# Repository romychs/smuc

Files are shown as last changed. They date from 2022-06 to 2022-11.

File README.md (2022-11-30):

# SMUC2

## Spectrum Multi Unit Controller

Оригинальный модуль SMUC (Scorpion & MOA Universal Controller), был расчитан на работу с клоном компьютера ZX Spectrum Scorpion.
Данный вариант является переработкой оригинальной схемы участниками форума zx-pk.ru и может использоваться с различными клонами, имеющими ZX-BUS.

Схема устройства основана на дискретной схеме SMUC Владислава Семченко (Vladislav Semchenko), реализована на CPLD фирмы ALTERA Евгением Ивановым (Ewgeny Ivanoff).
Некоторые изменения в схеме добавлены для увеличения совместимости с современными машинами (ZXM-Phoenix и др.) Валерием Ткачуком (Valery Tkachuck).
Печатная плата разработана и изготовлена Дмитрием Михальченковым (Dmitry Mikhalchenkov).

В папке [Originals](Originals) собраны материалы по варианту контроллера, разработанному участниками форума zx-pk.ru.

[Тема на форуме SMUC на дискретах и ПЛИС](https://zx-pk.ru/threads/1360-smuc-na-diskretakh-i-plis.html)

## Возможности контроллера
* Интерфейс IDE для подключения HDD, CD
* Память NVRAM 2k, для сохранения настроек
* Энергонезависимые часы типа DS1287, DS12887, M146818, 512ВИ1.
* Проограммная совместимость с ранее выпускавшимся SMUC 1.X, фирмой Scorpion, за исключением контроллера прерываний и интерфейса ISA8, которые в данной реализации отсутствуют.

## Мой вариант
В папке [My](My), приведена оцифрованая мной схема, печатная плата и герберы.

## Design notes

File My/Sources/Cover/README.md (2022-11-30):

# SMUC2

Декоративная крышка для платы SMUC2 в формате STL. Подходит только для моей версии платы, на других не проверял.

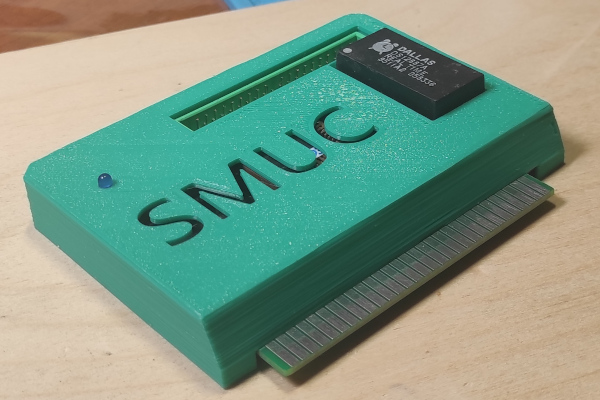
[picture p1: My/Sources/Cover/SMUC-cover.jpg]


Отпечатана на 3D-принтере:
* Пластик: PLA
* Сопло: 0.4мм
* Слой: 0.2мм
* Печать без поддержек, буквами SMUC вниз к столу.

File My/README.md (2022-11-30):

# SMUC2

Оцифрованная мной в EasyIDA схема контроллера SMUC2.

Схема, практически соответствует оригинальным герберам с исправлением замеченных ошибок. 
Печатная плата немного доработана, укорочены дорожки, передвинуты некоторые элементы, для более удобного монтажа, плата залита земляными полигонами.
Шаг ламелей краевого разъема 2.54мм под современные разъемы SL60 и SL62.

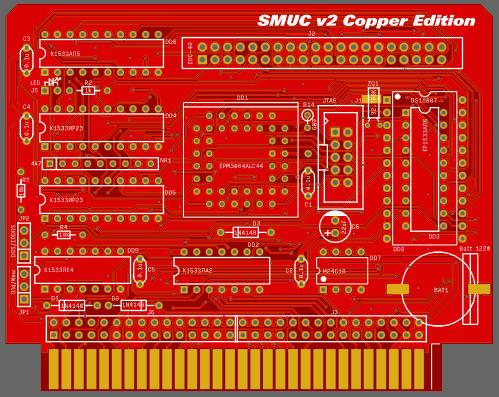
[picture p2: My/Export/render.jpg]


[Схема и печатная плата](Export)

[Герберы](Gerbers)

[Исходники для EasyEDA](Sources)

Все, что мое, то под лицензией BSD-3.

* Исправлена ошибка с сигналом SDA, замеченая VGalex.

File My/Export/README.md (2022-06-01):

# SMUC2

Схемы и монтажка в форматах PDF.

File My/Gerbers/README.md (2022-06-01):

# SMIC2

При заказе платы, не забудте указать, что плата имеет контакты на краю платы и нужен скос, для удобства вставки платы в слот.

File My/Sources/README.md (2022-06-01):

# SMUC2

Исходники проекта в [EasyIDA:](https://easyeda.com/)

Как использовать:
В редакторе, кликнуть на тулбаре в меню "Document" > "Open" > "EasyEDA Source", и выберите json-файл.

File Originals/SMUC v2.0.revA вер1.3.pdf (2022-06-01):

# SMUC v.2.0

rev.A

Руководству по подключению

http://witchcraft.org.ua/
http://zx.pk.ru/

Данное | руководство | поставляется | вместе | с | контроллером
SMUC v.2.0 rev.A.
В руководстве освещены вопросы подключения контроллера SMUC к ZX-Spectrum совместимому компьютеру, приведены монтажная и принципиальная схемы устройства, распиновка разъемов расширения по стандарту ZX-BUS. Описаны порты контроллера и принципы их программирования.
Составил | Михальченков | Дмитрий | Александрович | (Dmitry
Mikhalchenkov). Дата последней редакции 21.10.2009 г.

### 1 Введение

В данном документе описан переработанный вариант схемы SMUC (Scorpion & MOA Universal Controller). Теперь аббревиатура SMUC означает Spectrum Multi Unit Controller и рассчитана не только на компьютеры ZS Scorpion, а и на любые другие, соответствующие стандарту ZX-BUS. В отличие от оригинального SMUC, из схемы изъяты узлы, связанные с поддержкой ISA-шины и контроллера прерываний (PIC).
Схема устройства основана на дискретной схеме SMUC [1] Владислава Семченко (Vladislav Semchenko), реализована на CPLD фирмы ALTERA Евгением Ивановым (Ewgeny Ivanoff). Некоторые изменения в схеме добавлены для увеличения совместимости с современными машинами (ZXM-Phoenix и др.) Валерием Ткачуком (Valery Tkachuck). Печатная плата
разработана | и | изготовлена | Дмитрием | Михальченковым | (Dmitry
Mikhalchenkov).
Обсуждение сборки и наладки устройства проводится на форуме «Speccy - наш выбор!» [2].
Об использовании контроллера см. фирменное руководство «SMUC. Универсальный контроллер HDD, CMOS, NVRAM, IBM периферии. Руководство по подключению и работе» [3].

### 2 Назначение контроллера

Контроллер SMUC (Spectrum Multi Unit Controller) v2.0 rev.A служит для подключения к Spectrum-совместимому компьютеру накопителей на жестких (HDD), лазерных дисках (CD и DVD) и карт памяти CompactFlash (при использовании переходника CF>IDE), оснащенных интерфейсом IDE, позволяет работать с ними в системах TR-DOS¹
| | | | , Is-DOS, CP/M.
Кроме этого, контроллер оснащен микросхемой энергонезависимой памяти (NVRAM) объемом 2 Кбайта, предназначенной для сохранения различных настроек компьютера, параметров HDD, переменных Теневого Сервис-Монитора (при использовании на ПК Scorpion ZS 256) и т. д. В контроллере предусмотрена установка микросхемы энергонезависимых часов типа DS1287, DS12887, M146818, 512ВИ1.
Контроллер программно совместим с ранее выпускавшимся SMUC 1.X, фирмой Scorpion, за исключением контроллера прерываний и интерфейса ISA8, которые в данной реализации отсутствуют.

1 Перечисленный функционал доступен при установленном ПрофПЗУ. В противном случае необходимо пользоваться сторонним программным обеспечением и драйверами.

### 3 Принципиальная схема контроллера

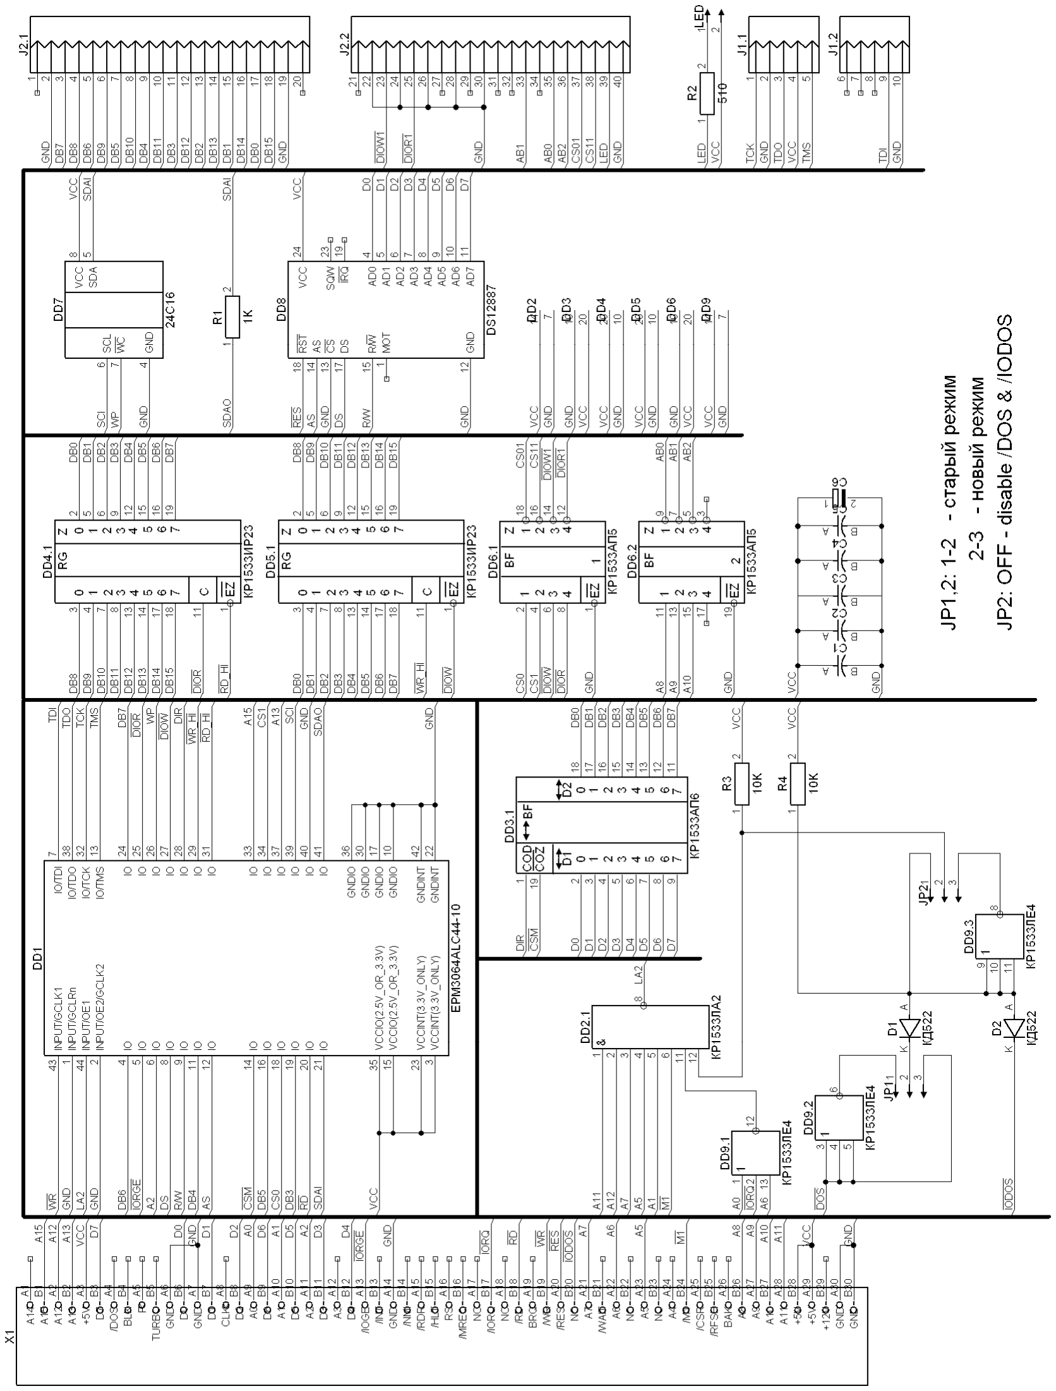
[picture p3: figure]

Рис. 1 – Принципиальная схема

Табл. 1. Список элементов
Обозначение на схеме | Наименование элемента
DD1 | EPM3064ALC44-10
DD2 | КР1533ЛА2
DD3 | КР1533АП6
DD4, DD5 | КР1533ИР23
DD6 | (КР555) КР1533АП5
DD7 | AT24C16
DD8 | DS12887
DD9 | КР1533ЛЕ4
D1, D2 | КД521
R1 | 1К 0,125Вт
R2 | 510 0,125Вт
R3, R4 | 10К 0,125Вт
С1 – С5 | 0,1мкФ
С6 | 10мкФ × 16В
J1 | IDC2X5M
J2 | IDC2X20M
J3² | HDR-2X30
LED | АЛ307
JP1, JP2 | JP1X3

### 4 Монтажная схема контроллера

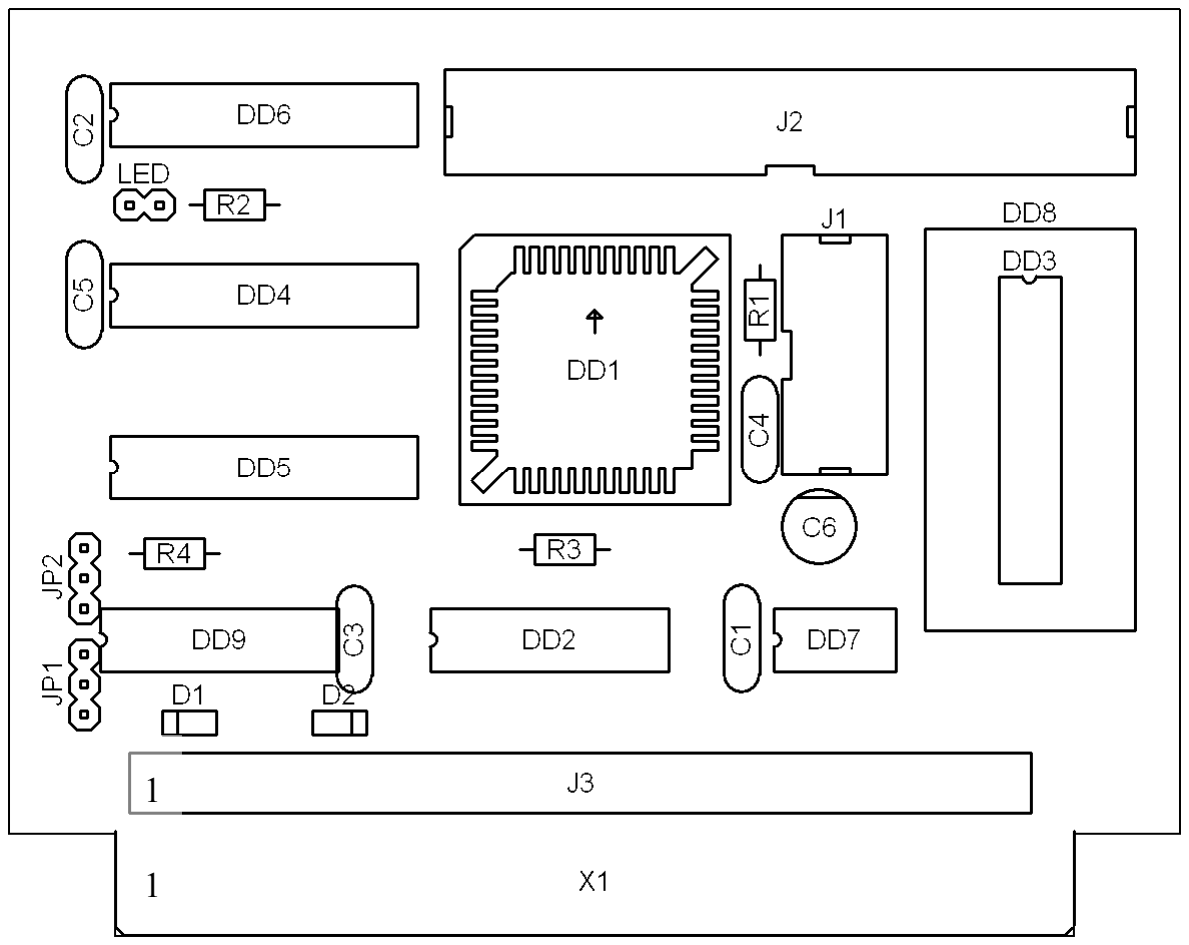
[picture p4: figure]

Рис. 2 – Монтажная схема

2 Штыревой разъем J3 на схеме не указан, на плате включается параллельно краевому разъему X1.

Первый контакт разъемов X1 и J3 находится слева.
Назначение разъемов:
— X1 — краевой ламельный разъем для подключения к системному разъему платы (см. Рис. 3);
— J1 — 10-контактный | штыревой | разъем | для | подключения
внутрисхемного программатора ByteBlaster, для программирования ПЛИС (см. Табл. 2) [4];
— J2 — 40-контактный стандартный разъем для подключения устройств IDE (см. Табл. 3);
— J3 — 60-контактный штыревой разъем для подключения к системному разъему платы (см. Рис. 3), включен параллельно разъему X1;
— JP1 и JP2 — 2-позиционные джампер-перемычки - селектор DOS режима с поддержкой сигнала /IODOS шины NemoBus v1.1 (инверсное значение D7 #EFF7). Селектор позволяет задавать режим активации портов контроллера (см. Табл. 4);
— LED — 2-контактный штыревой разъем для индикатора обращения к HDD (анод светодиода подключается к первому контакту, катод – ко второму).
Табл. 2. Распайка разъема
программатора ByteBlaster
Контакт | Сигнал | Назначение
1 | TCK | Тактовый сигнал
2 | GND | Сигнальная земля
3 | TDO | Данные с ПЛИС
4 | VCC | Напряжение питания
5 | TMS | Контроль автомата JTAG
6 | - | Не используется
7 | - | Не используется
8 | - | Не используется
9 | TDI | Данные в ПЛИС
10 | GND | Сигнальная земля
Табл. | 3. | Разъем | для
подключения IDE устройств
Контакт | Цепь | Контакт | Цепь
1 | Reset | 2 | GND
3 | D7 | 4 | D8
5 | D6 | 6 | D9
7 | D5 | 8 | D10
9 | D4 | 10 | D11
11 | D3 | 12 | D12
13 | D2 | 14 | D13
15 | D1 | 16 | D14
17 | D0 | 18 | D15
19 | GND | 20 | Свободный
21 | DRQ3 | 22 | GND
23 | IOWR | 24 | GND
25 | IORD | 26 | GND
27* | CRDY | 28 | CSEL
29* | DACK3 | 30 | GND
31* | IRQ14 | 32* | IO16
33 | ADR1 | 34* | PDIAG
35 | ADR1 | 36 | ADR2
37 | CS1 | 38 | CS3
39* | DA/SP | 40 | GND

* обозначены сигналы неиспользуемые при работе контроллера

Табл. 4. Перемычки для установки режима адресации контроллера
Положение перемычек | Описание
| Адресация контроллера в теневом режиме сигналом /DOS
| Адресация контроллера в теневом режиме сигналом /DOS или /IODOS
| Адресация контроллера в стандартном режиме (без учета сигналов /DOS и /IODOS)
1 | 2 | 3 | 1 | 2 | 3
| JP1 | | | JP2
1 | 2 | 3 | 1 | 2 | 3
| JP1 | | | JP2
1 | 2 | 3 | 1 | 2 | 3
| JP1 | | | JP2

Платы изготавливались на заводе без проверки. Перед сборкой внимательно осмотрите плату на наличие залипов между проводниками. Если они есть, обязательно их удалите. Также осмотрите контакты краевого разъема, наличие заусенцев может замкнуть контакты разъема при установке на материнскую плату.

При установке контроллера на материнскую плату, обязательно проверяйте совпадение контактов разъема контроллера и материнской платы. Перекосы и смещения недопустимы и могут привести к выходу контроллера и/или материнской платы из строя.

### 5 Подключение контроллера

Подключение контроллера к компьютеру предусмотрено посредством установки в слот расширения по стандарту ZX-BUS (Nemo-Bus). Для этого на плате контроллера размещен краевой ламельный разъем X1, шаг следования контактов – 2.54 мм, и штыревой разъем J3, если на материнской плате не предусмотрены слоты подключения.
В настоящее время шиной ZX-BUS оснащены следующие компьютеры:
- Kay-1024 3SL;
- Scorpion ZS 256;
- Pentagon 1024 SL;
- ZXM-Phoenix.
При установке платы контроллера в слот, удостоверьтесь, что плата расположена правильно, для этого обратитесь к документации Вашего компьютера. На компьютерах Kay-1024 и Scorpion ZS 256 контроллер вставляется в разъем платы так, что бы детали контроллера “смотрели” в сторону центрального процессора Z80.

Вид со стороны деталей

A14
A12
+5v
/DCDOS (3)
(2)
GND
GND
RAS (4)
A0
A1
A2
A3
/IORQCE
GND (kay!) (7)
/CSROMCE
RS (kay!) (5)

/BUSRQ
/RES
A7
A6
A5
A4
/CSROM
/BUSAK
A9
A11
+5v (kay!) (7)
GND

A15

D7

A13

/CSDS (1)

D0
D1
D2

AB
1 | 1
2 | 2
3 | 3
44
55
6 | 6
7 | 7
8 | 8
99
10 | 10
11 | 11
12 | 12
13 | 13
14 | 14
15 | 15
16 | 16
17 | 17
18 | 18
19 | 19
20 | 20
21 | 21
22 | 22
23 | 23
24 | 24
25 | 25
26 | 26
27 | 27
28 | 28
29 | 29
30 | 30
AB

D6
D5

TURBO (kay!) (6)

D3
D4
/INT
/NMI
/HALT
/MREQ
/IORQ
/RD
/WR

/WAIT

/M1
/RFSH
A8
A10
+5v (kay!) (7)
+12v (kay!) (7)
GND

Примечания:

(kay!) -- сигнал подключен только в компьютере KAY

(1) -- подключение 0 страницы ОЗУ (0xc000..0xffff в режиме zx-48kb) вместо ПЗУ. Сигнал имеется только в компьютерах Scorpion и KAY.
(2) -- контакт имеет разные назначения в разных моделях компьютеров.
В компьютере ZS-Scorpion ранних выпусков отмечен как РЕЗЕРВHЫЙ. Позже использовалься для подачи питания +12V на платы расширений. Hа turbo платах (зеленых) неиспользуемый контакт. В компьютере KAY на этот контакт выводится сигнал тактовой частоты 14Mhz.
(3) -- сигнал индицирующий подключение ПЗУ и портов Beta-Disk интерфейса.
(4) -- в компьютере Scorpion это и сигнал тактовой частоты процессора, и инвертированный и задержанный сигнал /RAS управляющий динамическим ОЗУ (по схеме Ленинград). В turbo версиях ZS-Scorpion сигнал не синхронный с тактовой частотой процессора. В компьютере KAY этот сигнал не является синхронным с тактовой частотой процессора и представляет из себя инвертированный сигнал /RAS. Частота всегда 3.5Mhz.
(5) -- сигнал имеется только в компьютере KAY. Это выход регистра 7FFD, отвечающий за банк ПЗУ (basic-128 или basic-48). Может управляться внешним устройством.
(6) -- сигнал устанавливается в 1 при включенном турбо-режиме. Выход типа открытый коллектор, то есть устройство расширения может принудительно отключить турбо-режим. Сигнал используется только в KAY.
(7) -- в компьютере ZS-Scorpion контакт не используется, используется только в KAY.
Рис. 3 – Сигналы шины ZX-BUS

Остальные Spectrum-совместимые машины либо имеют иную шину расширения, либо не имеют её вовсе. Для подключения контроллера к таким компьютерам, требуется произвести некоторые доработки на плате компьютера [5].
После подключения контроллера к системной плате компьютера необходимо подключить шлейф от IDE-устройства к разъему J2 контроллера. Подключение производится плоским 40 жильным кабелем.
Большинство шлейфов ATA содержат ключ (пломба вместо 20 контакта разъема шлейфа и отсутствующий штырек на разъеме контроллера), который позволяет избежать неправильное подключение устройств. Однако встречаются старые или самодельные шлейфы без ключа, будьте внимательней, проверьте, что подключение производится контакт в контакт, то есть 1-ый контакт к первому, 2-ой — к 2-му и т.д.
При необходимости подключите к разьему X6 светодиод типа АЛ307, плюс светодиода подсоединяется к конт. 2, минус к — конт. 1

### 6 Установка часов реального времени (СМОS-часов)

В стандартном варианте SMUC-контроллер поставляется без микросхемы часов реального времени (DS1287/DS12887), но при желании
пользователю | необходимо | только | вставить | эту | микросхему | в
соответствующую панельку на плате контроллера.
Эти микросхемы уже имеют встроенный генератор импульсов и источник резервного питания. Фирмой изготовителем гарантируется надежная работа источника в течении 10 лет. Следует помнить, что наличие или отсутствие ИМС часов никак не влияет на работу контроллера с HDD. Все установки параметров HDD и другие переменные, используемые Теневым Сервис-Монитором, и назначаемые пользователем, хранятся в ИМС
энергонезависимой | памяти | (NVRAM), | устанавливаемой | на | всех
контроллерах. Никаких дополнительных источников для работы NVRAM не требуется.
Микросхема DS1287/DS12887 может быть заменена импортными микросхемами других фирм производителей, а также советским аналогом — 512ВИ1 (при соответствующей доработке) [2].

### 7 Программирование SMUC

### 7.1 Распределение портов SMUC

Выборка SMUC как в оригинальной, так и переработанной (данной) схеме происходит в соответствии со значениями в Табл. 5:
Табл. 5. Условия выборки SMUC
/M1 /IORQ/DOS A15 A14 A13 A12 A11 A10 | | | | | | | | | A9 | A8 | A7 | A6 | A5 | A4 | A3 | A2 | A1 | A0
1 | 0 | 0 | DC | ISA | DC | 1 | 1 | DC | DC | DC | 1 | DC | 1 | ISA | ISA | DC | 1 | 0
Пояснения к таблице:
“1” и “0” – логическое значение соответствующих сигналов;
“DC” – сигнал используется в схеме для дешифровки портов базовых устройств SMUC и устройств ISA;
“ISA” – сигнал используется для дешифровки портов устройств ISA, в данной схеме не используется и по умолчанию принимается равным “1”; Для большинства базовых устройств SMUC сигналы A10, A9, A8 по умолчанию принимается равным “1”. Порты базовых устройств SMUC и устройств ISA дешифруются по сигналу A6: A6 = “0” – SMUC, A6 = “1” – ISA.
Выборка конкретных устройств происходит в соответствии со значениями Табл. 6 и Табл. 7 (действительно только для оригинального SMUC). При этом должно соблюдаться следующее условие: /M1 = “1”, /IORQ = “0”, /DOS = 0.

Табл. 6. Условия выборки базовых устройств SMUC
A15 | A14 | A13 | A12 | A11 | A10 | A9 | A8 | A7 | A6 | A5 | A4 | A3 | A2 | A1 | A0 | Порт | Устрой-ство
0 | 1 | 0 | 1 | 1 | 1 | 1 | 1 | 1 | 0 | 1 | 1 | 1 | 0 | 1 | 0 | #5FBA | VER
0 | 1 | 0 | 1 | 1 | 1 | 1 | 1 | 1 | 0 | 1 | 1 | 1 | 1 | 1 | 0 | #5FBE | REV
0 | 1 | 1 | 1 | 1 | 1 | 1 | 1 | 1 | 0 | 1 | 1 | 1 | 0 | 1 | 0 | #7FBA | FDD
0 | 1 | 1 | 1 | 1 | 1 | 1 | AB0 | 1 | 0 | 1 | 1 | 1 | 1 | 1 | 0 | #7FBE | PIC
1 | 1 | 0 | 1 | 1 | 1 | 1 | 1 | 1 | 0 | 1 | 1 | 1 | 0 | 1 | 0 | #DFBA | RTC
1 | 1 | 0 | 1 | 1 | 0 | 0 | 0 | 1 | 0 | 1 | 1 | 1 | 1 | 1 | 0 | #D8BE | IDE-HI
1 | 1 | 1 | 1 | 1 | 1 | 1 | 1 | 1 | 0 | 1 | 1 | 1 | 0 | 1 | 0 | #FFBA | SYS
1 | 1 | 1 | 1 | 1 | AB2 | AB1 | AB0 | 1 | 0 | 1 | 1 | 1 | 1 | 1 | 0 | #FFBE | IDE

Табл. 7. Условия выборки устройств ISA
A15 A14 A13 A12 A11 A10 | | | | | A9 | A8 | A7 | A6 | A5 | A4 | A3 | A2 | A1 | A0 | Порт | Устрой-ство
0 | AB4 AB3 | 1 | 1 | AB2AB1 AB0 | | | 1 | 1 | 1 | AB6AB5 | | 1 | 1 | 0 | #18E6 -#7FFE | ISA

ISA-шина SMUC поддерживает только карты расширения XT-ISA (или ISA-8), при этом адресные биты AB0-AB6 формируются из адресных сигналов процессора Z80, адресные биты AB7 и AB8 определяются битами данных порта #FFBA, а состояние адресных бит AB9-AB19 всегда установлено в “1”. Таким образом, поддержанными оказываются только 8-битные карты и устройства ISA с адресами 200h-3FFh (ранние ISA-карты использовали в дешифровке только адресные линии AB0-AB9). В адресном пространстве портов Z80 эти устройства занимают адреса #18E6 - #7FFE. Для простоты можно условно считать, что адреса устройств ISA формируются комбинацией одного из старших байт адреса #18, #38, #58 или #78 и одного из младших байт адреса #E6, #EE, #F6 или #FE (адресные биты AB0-AB2 дешифруют конкретный регистр устройства ISA).
Следует заметить, что явно видно “пересечение” адреса порта клавиатуры ZX-Spectrum #7FFE (клавиши “Space”, “SimbolShift”, “M”, “N”, “B”) с портами ISA 27Fh, 2FFh, 37Fh, 3FFh.

### 7.2 Описание портов SMUC

Ниже будет приведено описание портов базовых устройств SMUC, далее просто устройства SMUC.

### 7.2.1 Порты версии #5FBA (VER) и ревизии #5FBE (REV)

Являются только портами чтения и служат для идентификации SMUC. При отсутствии, по крайней мере, порта #5FBA подсистема ПрофПЗУ не “видит” SMUC и в дальнейшем работать с ним отказывается. Номер версии и ревизии задается битами D7, D6, D5 и D3 портов #5FBA и #5FBE. Формат

числа (номера) одинаков для обоих портов и указан в Табл. 8. Следует отметить, что номер версии (значение считанное из порта #5FBA) не может быть равным 7, так как именно в этом случае подсистема ПрофПЗУ признает отсутствие устройств SMUC в системе. Ниже приведены процедуры работы с портами версии (имеются в виду порты #5FBA и #5FBE).

Лис. 1 – Процедуры работы с портами версии

;----------------------------------------------------------------------------;Описание: Проверка наличия SMUC по определению версии
;входные данные: нет
;выходные данные: флаг CY - установлен - платы нет
; | D - байт версии
; | E - байт ревизии
;----------------------------------------------------------------------------
LAB_2425: | call | 0d51h
2428 3817 | jr | c,LAB_2441
242a 01ba5f | ld | bc,5fbah
242d ed78 | in | a,(c) | ;чтение байта версии
242f 3c | inc | a
2430 280f | jr | z,LAB_2441;флаг Z установлен - платы нет
2432 3d | dec | a
2433 cd4324 | call | LAB_2443 ;преобразуем байт
2436 57 | ld | d,a
2437 01be5f | ld | bc,5fbeh
243a ed78 | in | a,(c) | ;чтение байта ревизии
243c cd4324 | call | LAB_2443 ;преобразуем байт
243f 5f | ld | e,a
2440 c9 | ret
LAB_2441: | scf
2442 c9 | ret
;----------------------------------------------------------------------------;Описание: Преобразование версии
;входные данные: А - до преобразования
;выходные данные: А - байт после преобразования ;----------------------------------------------------------------------------
LAB_2443: | ld | b,a
2444 0f | rrca
2445 0f | rrca
2446 0f | rrca
2447 e601 | and | 01h
2449 4f | ld | c,a
244a 78 | ld | a,b
244b 07 | rlca
244c 07 | rlca
244d 07 | rlca
244e b1 | or | c
244f e607 | and | 07h
2451 c9 | ret

### 7.2.2 Порт виртуальных дисководов #7FBA (FDD)

Порт доступен на запись и чтение. Порт представляет собой ячейку памяти на 2 бита. Назначение бит показано в Табл. 9.

Табл. 8. Формат номера
версии и ревизии SMUC
Значения бит данных
D7 | D6 | D5 | D3 | Номер
0 | 0 | 0 | 0 | 0
0 | 0 | 1 | 1 | 1
0 | 1 | 0 | 0 | 2
0 | 1 | 1 | 1 | 3
1 | 0 | 0 | 0 | 4
1 | 0 | 1 | 1 | 5
1 | 1 | 0 | 0 | 6
1 | 1 | 1 | 1 | 7

Табл. 9. Назначение бит
порта виртуальных дисководов Биты
порта
#7FBA

Назначение бит

D7 | Дисковод A: 0 – виртуальный; 1 - реальный
D6 | Дисковод B: 0 – виртуальный; 1 - реальный

7.2.3 Порты контроллера прерываний #7FBE/#7EBE (PIC).
Данные порты служат для обмена данными с микросхемой контроллера прерываний i8259A/i8259 (КР1810ВН59А/КР580ВН59). Это устройство используется только в оригинальном SMUC и в данной схеме не поддерживается, по той причине, что его основная задача заключалась в поддержке ISA-шины. Тем не менее, для полноты картины, тут приведены общие данные по контроллеру прерываний.
Управление микросхемой i8259A и ее аналогов производится через два порта – #7FBE/#7EBE. Назначение портов приведено в Табл. 10.

Табл. 10. Назначение портов PIC

Порт | Регистры PIC
OUT #7EBE | ICW1, OCW2, OCW3
OUT #7FBE | ICW2, ICW3,ICW4, OCW1(IMR)
IN #7EBE | IRR, ISR
IN #7FBE | IMR

Более детальную информацию по контроллеру прерываний i8259A следует искать в описании на микросхему.

7.2.4 Порт часов реального времени #DFBA (RTC).
Обмен данными с микросхемой CMOS RTC Motorola MC146818A или ее аналогами (Интеграл КР512ВИ1, Dallas DS1287, Benchmarq BQ3287 и др.) производится через два порта чтения/записи с адресом #DFBA. Выборка необходимого порта осуществляется битом D7 порта #FFBA. Назначение портов RTC приведено в Табл. 11.

Табл. 11. Назначение портов RTC
Бит D7 порта #FFBA | Порт | Регистр RTC
| OUT #DFBA IN #DFBA | Регистр адреса 0 Регистр данных
| OUT #DFBA IN #DFBA | Регистр данных 1 -

Функционально микросхема RTC представляет собой массив из 64-128 (в зависимости от типа микросхемы) регистров данных. Регистры #00-#0D используются для хранения значений времени и управления часами, а регистры #0E-#7F являются ОЗУ. Назначение регистров RTC приведено в Табл. 12.

Табл. 12. Назначение регистров RTC
Адрес регистра | Назначение
#00 | Секунды

#01 | Секунды будильника

#02 | Минуты

#03 | Минуты будильника

#04 | Часы

#05 | Часы будильника

#06 | День недели

#07 | Число

#08 | Месяц

#09 | Год

#0A | Регистр A

#0B | Регистр B

#0C | Регистр C

#0D | Регистр D

#0E-#7F | ОЗУ общего назначения

Более детальную информацию по RTC следует искать в описании на микросхему.

7.2.5 Порты ATA.
Для работы с устройствами ATA (HDD, CD/DVD-ROM, CF и др.) в SMUC имеется массив портов #F8BE-#FFBE (АТА) и регистр старшего байта данных #D8BE (IDE-HI). Кроме того, для выбора двух полукомплектов регистров ATA используется бит D7 порта #FFBA. Назначение и порты регистров ATA приведены в Табл. 13.

Табл. 13. Назначение регистров ATA
D7 порта #FFBA | Порт SMUC | Порт IBM PC | Адресация CHS | Адресация LBA(28) Бит
OUT | IN | OUT | IN
0 | #F8BE | 1F0h | Data | Data | Data | Data
| #F9BE | 1F1h | Features | Error | Features | Error
| #FABE | 1F2h | Sector Count | Sector Count | Sector Count | Sector Count
| #FBBE | 1F3h | Sector Number | Sector Number | LBA (7:0) | LBA (7:0)
| #FCBE | 1F4h | Cylinder Low | Cylinder Low | LBA (15:8) | LBA (15:8)
| #FDBE | 1F5h | Cylinder High | Cylinder High | LBA (23:16) | LBA (23:16)
| #FEBE | 1F6h | Device/Head | Device/Head | Device, LBA (27:24) | Device, LBA (27:24)
| #FFBE | 1F7h | Command | Status | Command | Status
1 | #FEBE | 3F6h | Device Control | Alternative Status | Device Control | Alternative Status

Регистр старшего байта данных #D8BE нужен для временного хранения четного байта данных. Поскольку регистр данных ATA (Data) 16-битный, то для согласования с 8-битной шиной данных Z80 требуется временный буфер в виде регистра IDE-HI.
Регистр #FEBE (Device/Head) имеет следующее значение бит:
D0-D3 – в режиме адресации CHS определяют номер головки, в режиме адресации LBA являются старшими битами логического адреса блока (сектора);
D4 – DEV (Device), выбор устройства, при DEV=0 выбрано ведущее, при DEV=1 – ведомое;
D5=1, устаревший;
D6 – L (LBA), режим адресации, L=0 – CHS, L=1 – LBA;
D7=1, устаревший.
Регистр #FEBE (Device Control) имеет следующее значение бит:
D0=0;
D1 – nIEN (Interrupt Enable), инверсный бит разрешения прерывания, nIEN=0 – выбранное устройство может вырабатывать сигнал INTRQ через тристабильный выход;
D2 – SRST (Software Reset), программный сброс, действует все время пока SRST=1. Оба устройства (Master и Slive) воспринимают этот сигнал одновременно. На ATAPI-устройства сигнал не влияет;
D3=1 – зарезервирован;

D4-D6=0 – зарезервированы;
D7 – HOB (High Order Byte), определен в режиме LBA48, любая запись в регистры командного блока (Command Block Registers) сбрасывает этот бит в 0. Для режимов CHS и LBA28 (обычный режим LBA) D7=0.
Более детальную информацию по работе устройств ATA следует искать в описании стандарта ATA.

### 7.2.6 Системный порт SMUC #FFBA (SYS)

Служит для аппаратного сброса ISA, PIC и АТА, управления адресными линиями AB7 и AB8 ISA-шины, управления PIC и NVRAM, а также выборки дополнительных регистров. Назначение битов порта SYS приведено в Табл. 14.
Табл. 14. Назначение бит порта SYS
Бит порта | OUT #FFBA | IN #FFBA
D0 | RESET, 0 – сброс ISA, PIC, ATA | -
D1 | AB7 ISA* | -
D2 | AB8 ISA* | -
D3 | IE (Interrupt Enable), 1 – разрешение прерываний от PIC* | ?
D4 | SDA I² C [OUT] | -
D5 | WP I² C(Write Protect), 1 – запрет записи | -
D6 | SCL I² C | SDA I 2 C [IN]
D7 | SR (Shadow Register), 1 – переключение на теневые регистры | IRQ1 [IN]

### 8 Гарантии и сервисное обслуживание

Платы контроллера поставляются в двух вариантах поставки:
- Пустая плата для самостоятельной сборки с документацией;
- Конструктор для самостоятельной сборки с прошитой микросхемой EPM3032/EPM3064 и документацией;
- Плата собранная и готовая к эксплуатации.
Все собранные платы тестируются на компьютерах Scorpion ZS-256 и Kay-1024. Т.е. пользователю они поставляются в рабочем состоянии.
Мы не несем ответственности в случае неправильной установки или подсоединения устройства к компьютеру или жесткому диску, повлекшему в результате этого, к выходу устройства или компьютера из строя.
При подключении жестких дисков стоит учитывать, что жесткие диски требовательны к источнику питания. Убедитесь, достаточно ли мощный Ваш блок питания для работы жесткого диска (требования по питанию обычно приводятся на корпусе жесткого диска).

### 9 Список литературы

1. В.В.Семченко «SMUC на дискретных компонентах», Харьков, 2006;
2. Форум «Speccy - наш выбор!», Тема «SMUC на дискретах и ПЛИС» http://zx.pk.ru/showthread.php?t=1360
3. SMUC. Универсальный контроллер HDD, CMOS, NVRAM, IBM периферии. Руководство по подключению и работе v.1.2. Фирма Скорпион & МОА. СПб, 1996-97;
4. Программатор "ByteBlaster". http://msevm.com/main/prog/bb2.htm
5. ZX-BUS. Spectrum Expert#1-2. 2002.
6. Контроллер IDE для ZX-BUS по схеме NEMO. NedoPC group, Москва, 2004;

### 10 Доработки и исправления на плате SMUC v2.0 rev.A

### 10.3 Добавление сигнала /DOS

В ревизии А плат имеется ошибка – сигнал /DOS не заведен с разъема в схему. Для исправления ошибки необходимо проводом типа МГТФ припаять перемычку между контактом A4 разъема X1 и ножками 3-4-5 микросхемы DD9.

### 10.4 Доработка для корректной работы на компьютерах с

шиной NemoBUS.
Платы ревизии А имеют ошибку в схеме формирования сигнала /IORGE, что приводит к конфликту между портами контроллера и материнской платы, при подключении к компьютерам, типа Kay-1024, ZXM-Phoenix 1024, Pentagon-1024 v2.2. На компьютерах Scorpion ZS-256 контроллер корректно работает как с, так и без доработки.
Для исправления ошибки необходимо выполнить следующие действия:
1. Отрезать сигнал /IORQ от ноги 2 DD9 ЛЕ4 (см. Рис.4, вид платы со стороны монтажа), на эту ногу подать "землю" (припаять перемычку проводом МГТФ между 7 и 2 ногами микросхемы DD9).
2. Отрезать от земли ногу 1 DD1 ALTERA EPM3032/EPM3064 (см. Рис.5, вид платы со стороны пайки) и подать на нее сигнал /IORQ с краевого разъема, контакт B17.
3. Прошить DD1 ALTERA EPM3032/EPM3064 с помощью ByteBlaster-MV последней прошивкой (см. http://witchcraft.org.ua/).

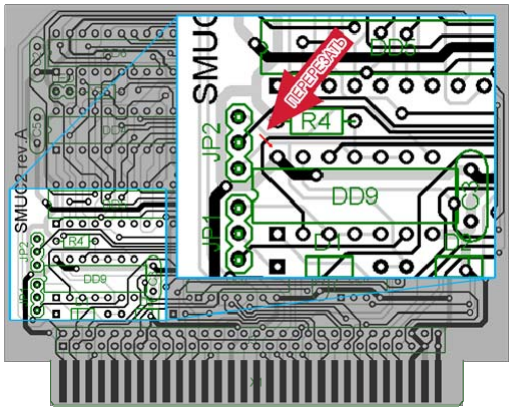
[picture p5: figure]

Рис. 4 – Доработка платы. Места разреза дорожек.

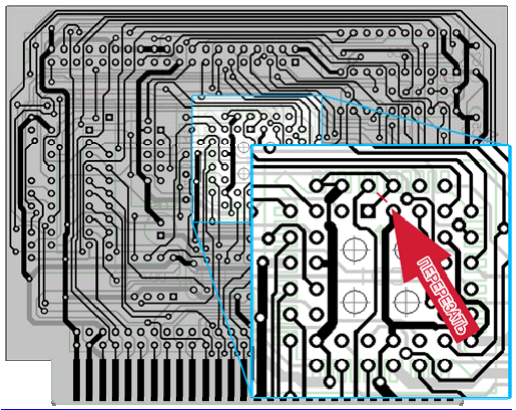
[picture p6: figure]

Рис. 5 – Доработка платы. Места разреза дорожек.

### 10.5 Повышение надежности работы жестких дисков

В разрыв сигналов /DIOR1 и /DIOW1, идущих на разъем IDE, необходимо поставить сопротивления на 27-100 Ом, которые уменьшают помехи на этих линиях, и увеличивает надежность работы жестких дисков. Схема должна выглядеть так:

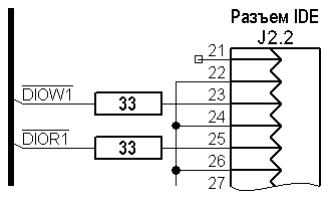
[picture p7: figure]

Рис. 6 – Повышение надежности работы жестких дисков

СОДЕРЖАНИЕ

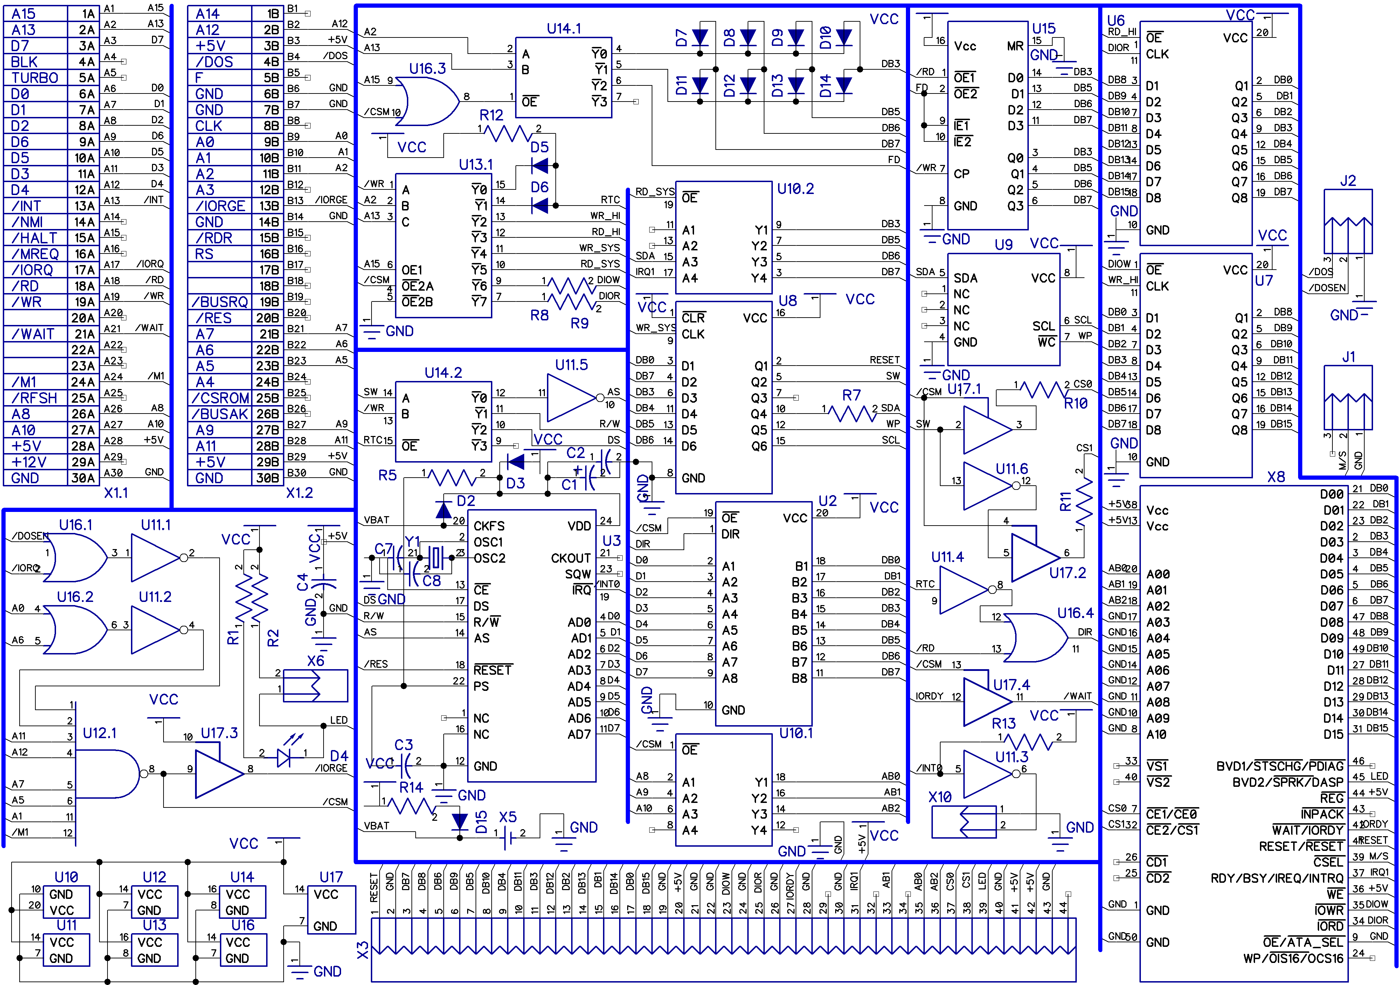
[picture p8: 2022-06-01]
Originals/Discrete/Schematics_From_krotan.gif

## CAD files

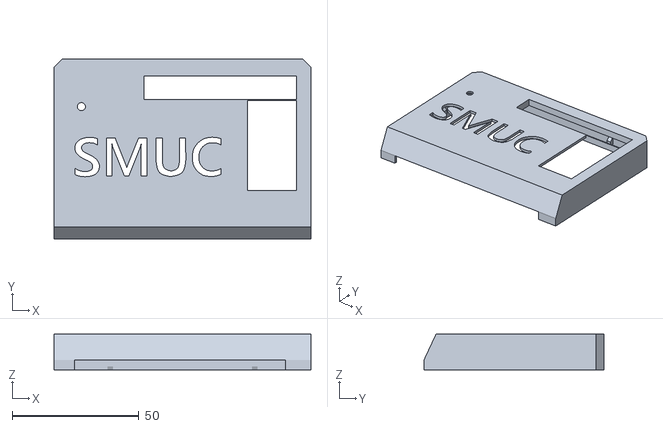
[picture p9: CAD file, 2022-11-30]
My/Sources/Cover/SmucCover.stl
101.4 x 71.0 x 14.2

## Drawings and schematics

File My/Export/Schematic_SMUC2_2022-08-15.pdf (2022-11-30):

## CPLD

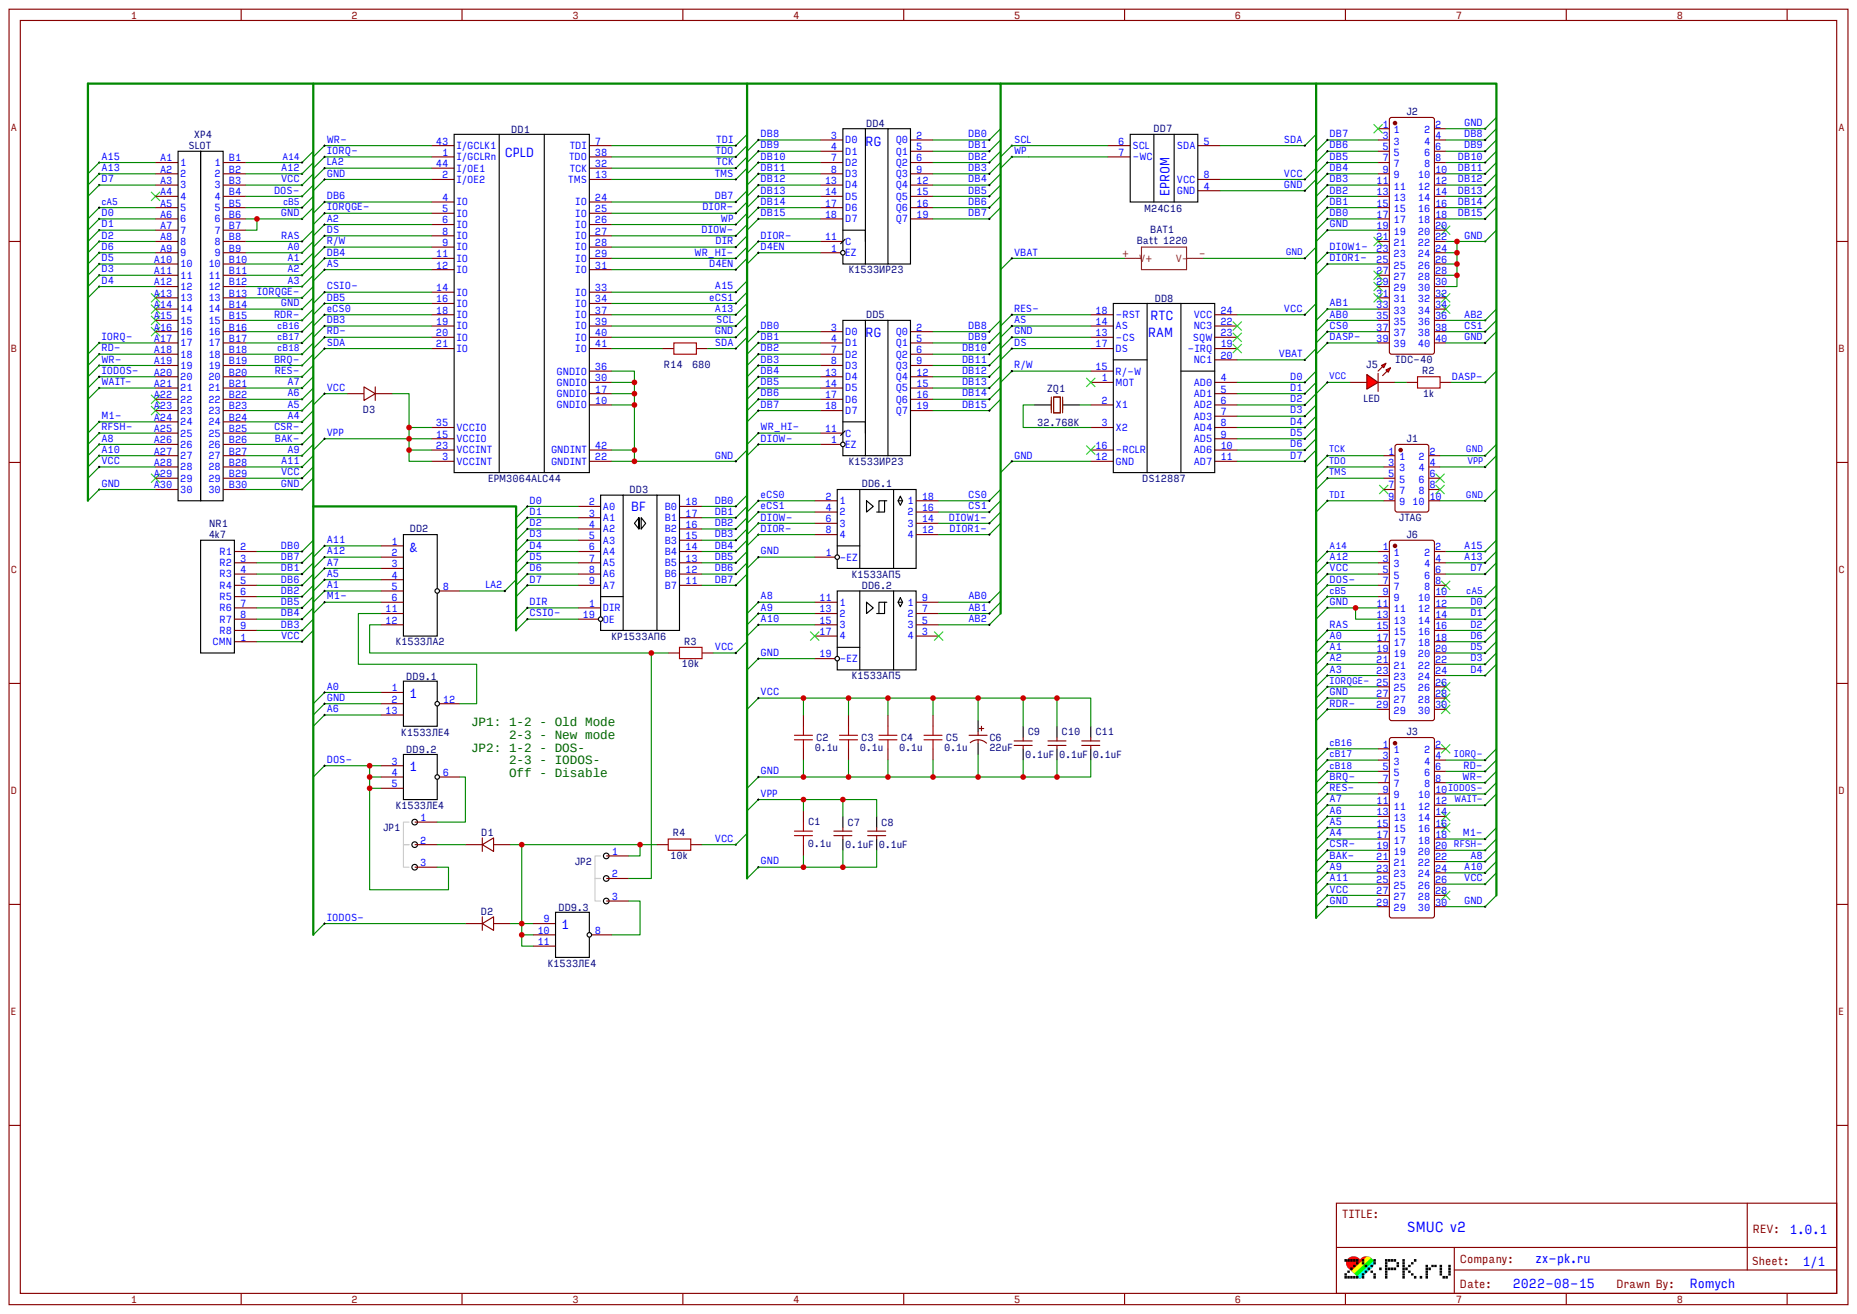
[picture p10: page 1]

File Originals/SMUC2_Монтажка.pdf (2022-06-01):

# SMUC v2.0 rev.B

## монтажная схема

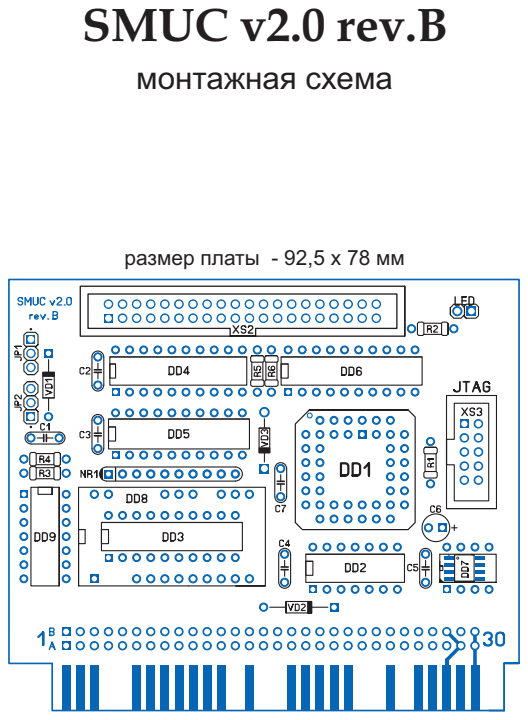
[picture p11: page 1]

размер платы - 92,5 х 78 мм

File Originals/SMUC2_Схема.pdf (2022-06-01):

# CPLD

3 | D0 4 | D1 7 | D2 8 | D3 13 | D4 14 | D5 17 | D6 18 | D7

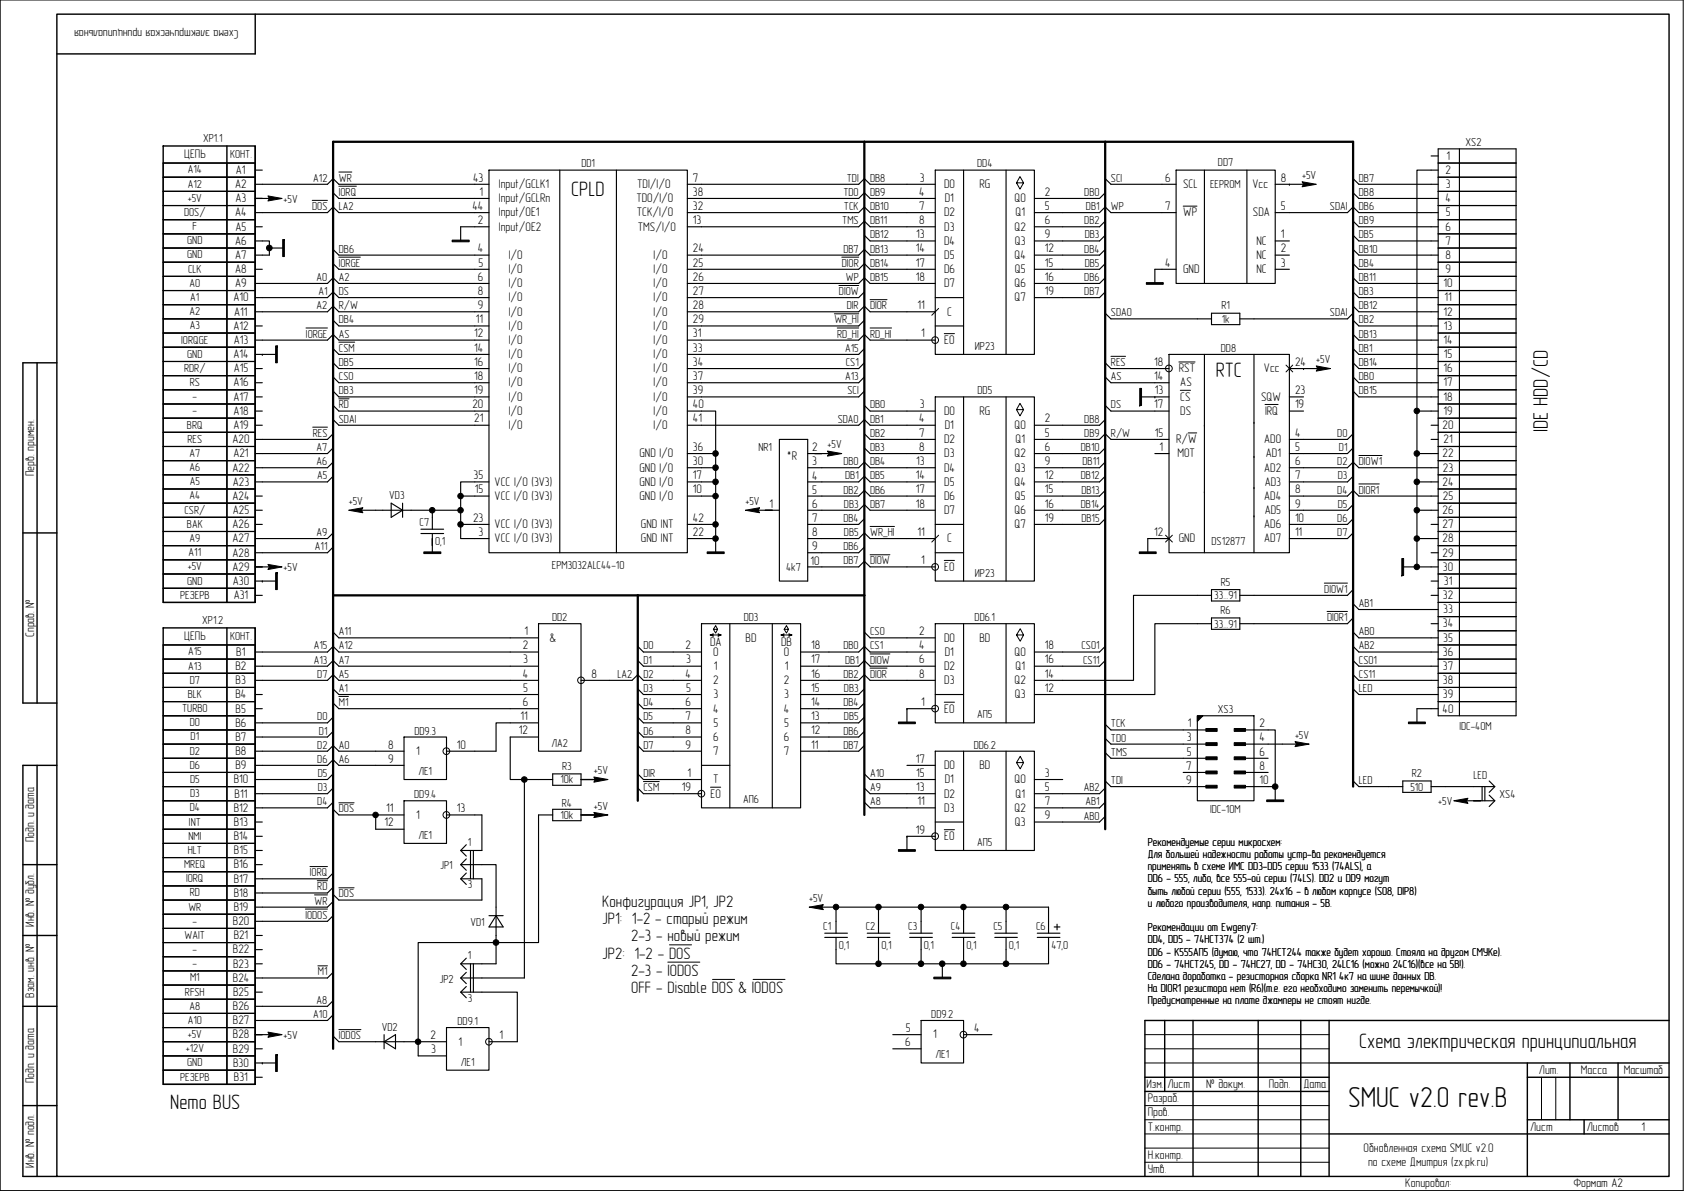
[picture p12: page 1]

Èíâ. ¹ ïîäë. Ïîäï. è äàòà Âçàì. èíâ. ¹ Èíâ. ¹ äóáë. Ïîäï. è äàòà Ñïðàâ. ¹ Ïåðâ. ïðèìåí.

NMI | B14
HLT | B15
MREQ | B16
IORQ | B17
RD | B18
WR | B19
- | B20
WAIT | B21
- | B22
- | B23
M1 | B24
RFSH | B25
A8 | B26
A10 | B27
+5V | B28
+12V | B29
GND | B30

Ðåêîìåíäóåìûå ñåðèè ìèêðîñõåì:
Äëÿ áîëüøåé íàäåæíîñòè ðàáîòû óñòð-âà ðåêîìåíäóåòñÿ
ïðèìåíÿòü â ñõåìå ÈÌÑ DD3-DD5 ñåðèè 1533 (74ALS), à
DD6 - 555, ëèáî, âñå 555-îé ñåðèè (74LS). DD2 è DD9 ìîãóò
áûòü ëþáîé ñåðèè (555, 1533). 24x16 - â ëþáîì êîðïóñå (SO8, DIP8)
è ëþáîãî ïðîèçâîäèòåëÿ, íàïð. ïèòàíèÿ - 5Â.

Ðåêîìåíäàöèè îò Ewgeny7:
DD4, DD5 - 74HCT374 (2 øò.)
DD6 - Ê555ÀÏ5 (äóìàþ, ÷òî 74HCT244 òàêæå áóäåò õîðîøî. Ñòîÿëà íà äðóãîì ÑÌÓÊå).
DD6 - 74HCT245, DD - 74HC27, DD - 74HC30, 24LC16 (ìîæíî 24C16)(âñå íà 5Â!).
Ñäåëàíà äîðàáîòêà - ðåçèñòîðíàÿ ñáîðêà NR1 4ê7 íà øèíå äàííûõ DB.
Íà DIOR1 ðåçèñòîðà íåò (R6)(ò.å. åãî íåîáõîäèìî çàìåíèòü ïåðåìû÷êîé)!
Ïðåäóñìîòðåííûå íà ïëàòå äæàìïåðû íå ñòîÿò íèãäå.

Ñõåìà ýëåêòðè÷åñêàÿ ïðèíöèïèàëüíàÿ

ÐÅÇÅÐÂ | B31

Èçì. | Ëèñò | ¹ äîêóì. | Ïîäï. | Äàòà
Ðàçðàá.
Ïðîâ.
Ò.êîíòð.

Îáíîâëåííàÿ ñõåìà SMUC v2.0
ïî ñõåìå Äìèòðèÿ (zx.pk.ru)

Í.êîíòð.

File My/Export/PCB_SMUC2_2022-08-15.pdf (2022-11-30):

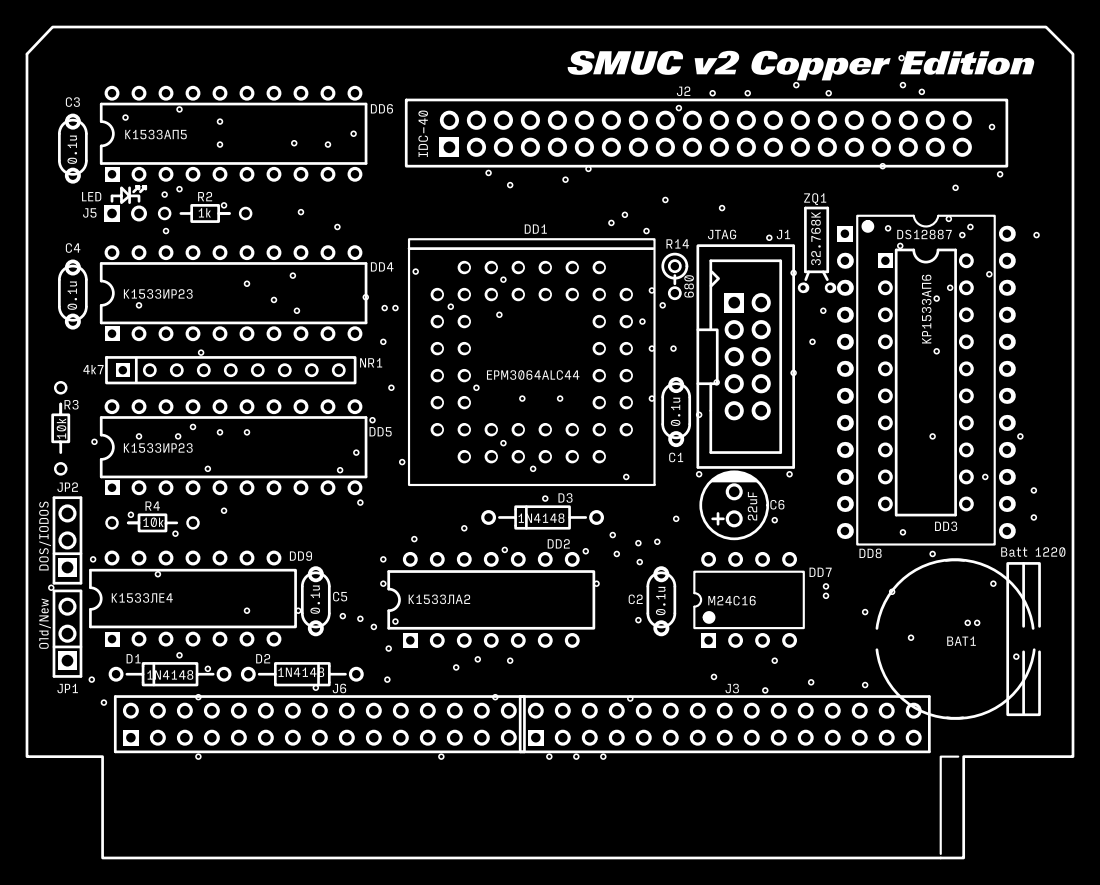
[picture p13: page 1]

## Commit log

2022-06-01 First version
    [SMUC2b_BOM.xls]
2022-11-30 SMUC cover
    [SmucCover.stl]
